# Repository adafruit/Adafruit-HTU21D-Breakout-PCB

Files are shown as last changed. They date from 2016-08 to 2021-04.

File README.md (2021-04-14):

## Adafruit HTU21D Breakout PCB
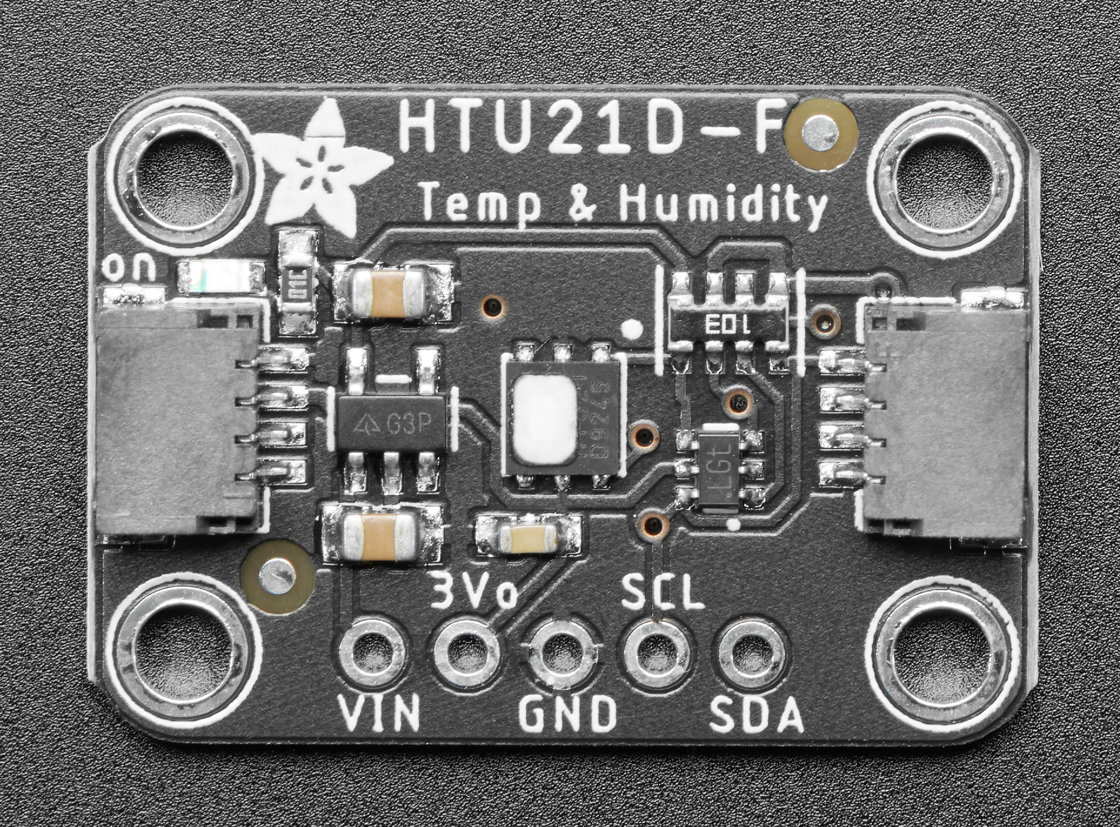
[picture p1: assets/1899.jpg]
<a href="http://www.adafruit.com/products/1899"><br/>
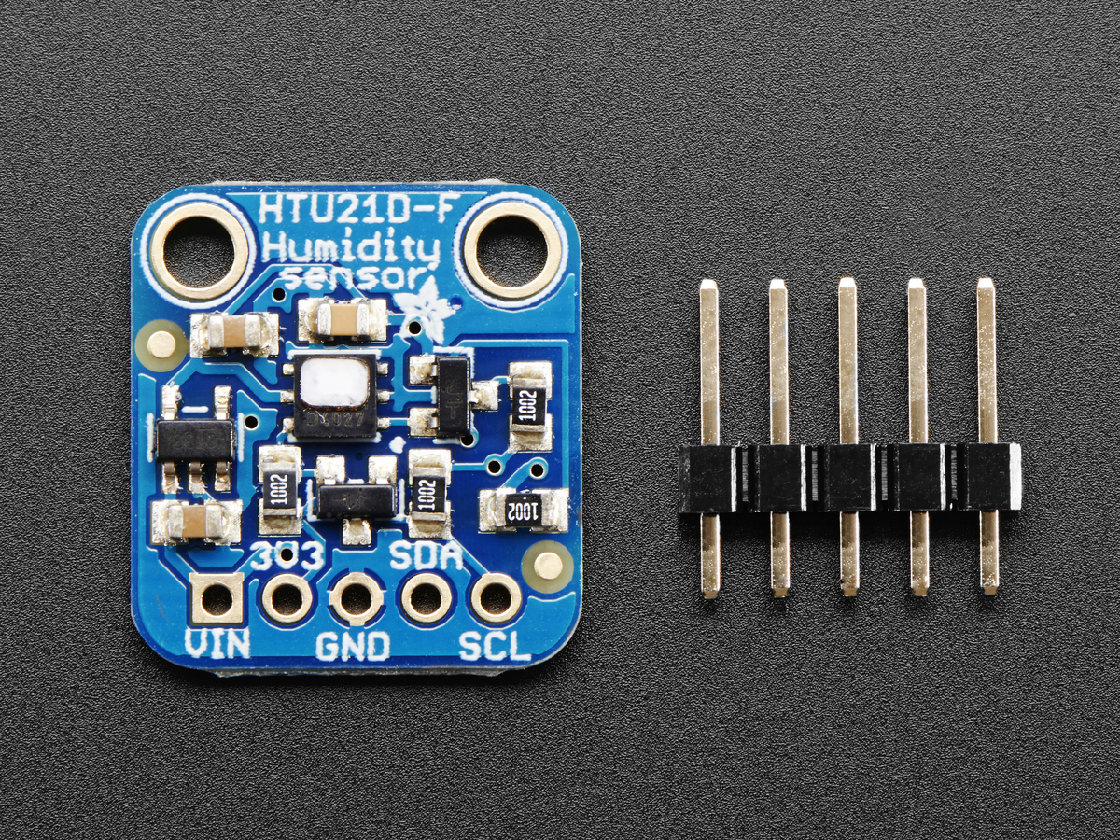
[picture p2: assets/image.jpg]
<a href="http://www.adafruit.com/products/1899"><br/>
Click here to purchase one from the Adafruit shop</a>

The HTU21D-F Temperature + Humidity Sensor - the best way to prove the weatherman wrong!

This I2C digital humidity sensor is an accurate and intelligent alternative to the much simpler Humidity and Temperature Sensor - SHT15 Breakout It has a typical accuracy of ±2% with an operating range that's optimized from 5% to 95% RH. Operation outside this range is still possible - just the accuracy might drop a bit. The temperature output has an accuracy of ±1°C from -30~90°C. If you're looking to measure temperature more accurately, we recommend the MCP9808 High Accuracy I2C Temperature Sensor Breakout Board.

To get you going fast, we spun up a custom made PCB in the STEMMA QT form factor, making them easy to interface with. The STEMMA QT connectors on either side are compatible with the SparkFun Qwiic I2C connectors. This allows you to make solderless connections between your development board and the HTU21Ds or to chain them with a wide range of other sensors and accessories using a compatible cable. QT Cable is not included, but we have a variety in the shop.

PCB files for the Adafruit HTU21D Breakout. The format is EagleCAD schematic and board layout
- https://www.adafruit.com/products/1899

### License

Adafruit invests time and resources providing this open source design, please support Adafruit and open-source hardware by purchasing products from [Adafruit](https://www.adafruit.com)!

All text above must be included in any redistribution

Designed by Limor Fried/Ladyada for Adafruit Industries.
Creative Commons Attribution/Share-Alike, all text above must be included in any redistribution. 
See license.txt for additional information.

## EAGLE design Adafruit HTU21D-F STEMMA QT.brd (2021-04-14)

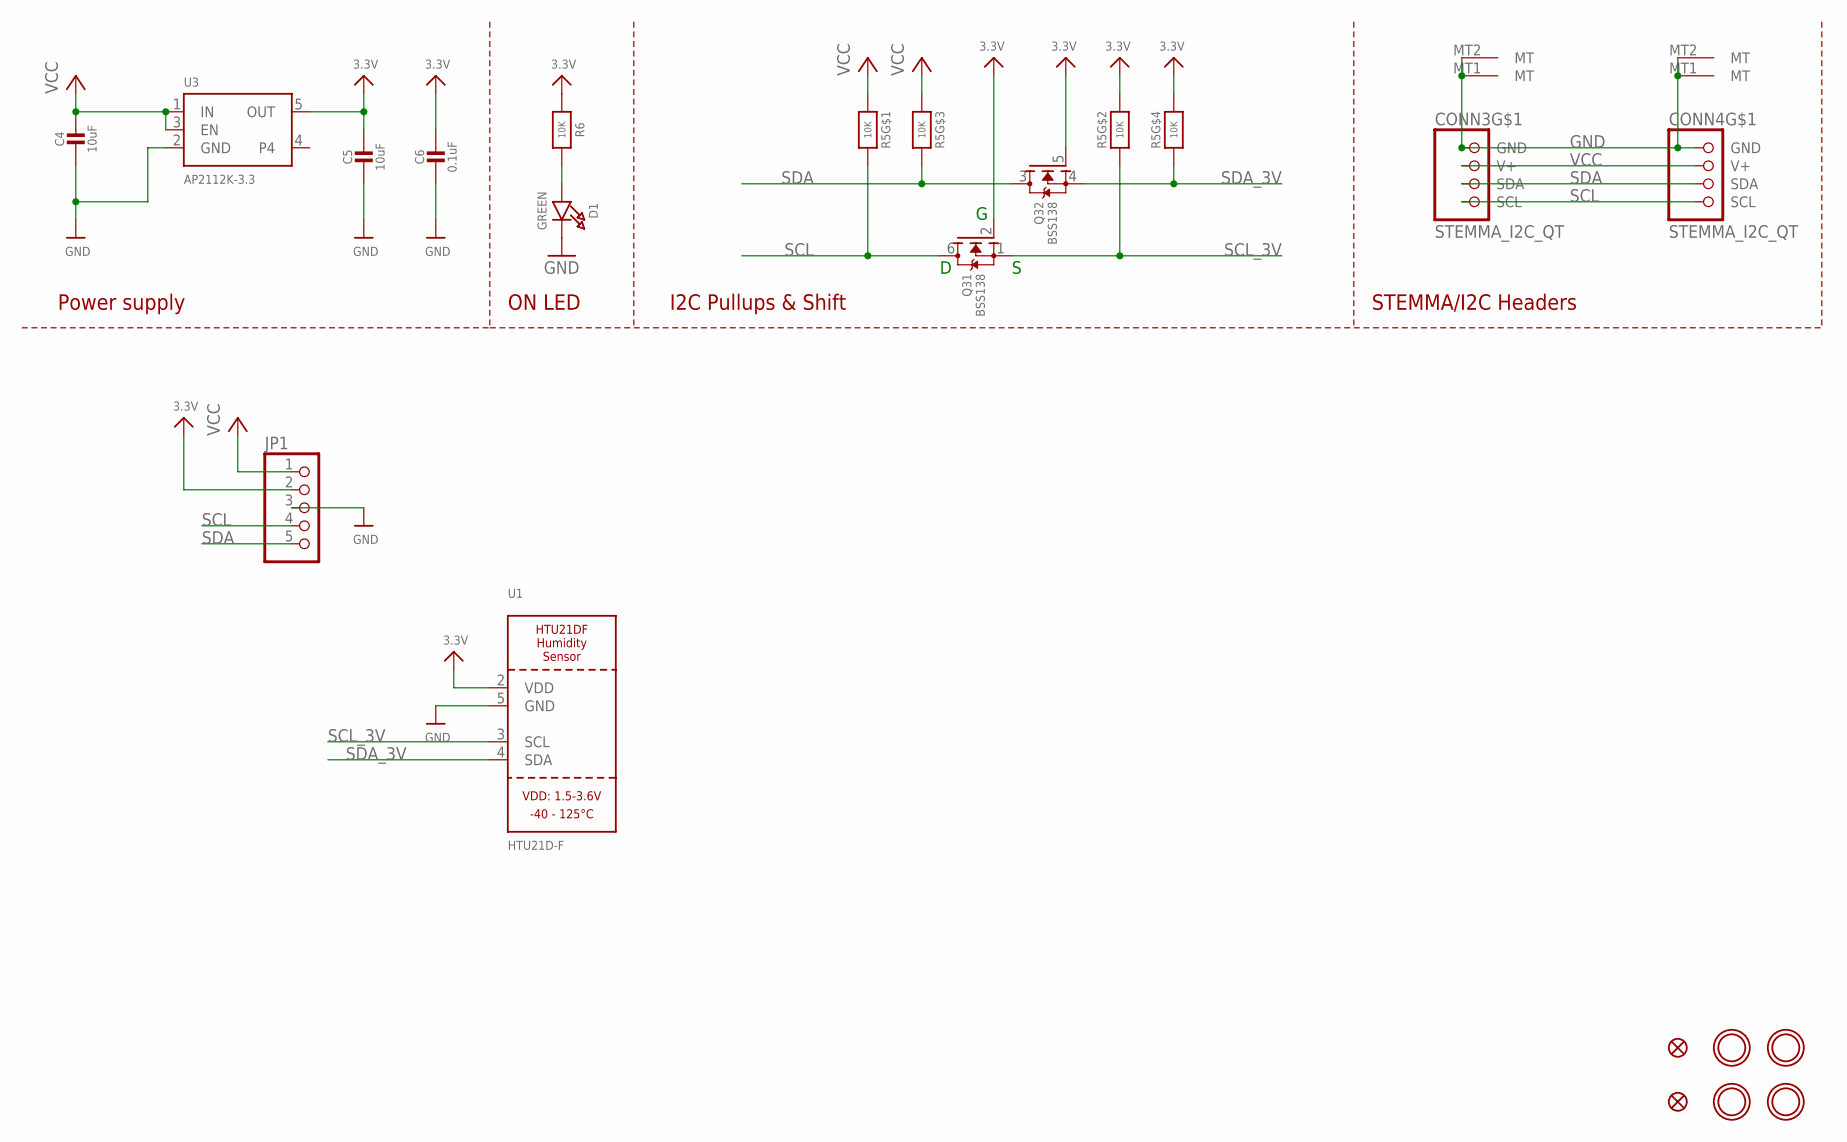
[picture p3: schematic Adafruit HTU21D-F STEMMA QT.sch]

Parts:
C4, C5: 10uF; 0805-NO
C6: 0.1uF; 0603-NO
CONN3, CONN4: STEMMA_I2C_QT; JST_SH4
D1: GREEN; CHIPLED_0603_NOOUTLINE
FID3, FID4: FIDUCIAL_1MM
JP1: HEADER-1X570MIL; 1X05_ROUND_70
Q3: BSS138; SOT363
R5: 10K; RESPACK_4X0603
R6: 10K; 0603-NO
U1: HTU21D-F; HTU21DF
U3: AP2112K-3.3; SOT23-5
U$19, U$20, U$22, U$25: MOUNTINGHOLE2.5; MOUNTINGHOLE_2.5_PLATED

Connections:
3.3V: C5.1, C6.1, JP1.2, Q3.2 (G), Q3.5 (G), R5.2 (1), R5.4 (1), R6.1, U1.2 (VDD), U3.5 (OUT)
GND: C4.2, C5.2, C6.2, CONN3.1 (GND), CONN3.MT1 (MT), CONN3.MT2 (MT), CONN4.1 (GND), CONN4.MT1 (MT), CONN4.MT2 (MT), D1.C, JP1.3, U1.5 (GND), U3.2 (GND)
unnamed: D1.A, R6.2
SCL: CONN3.4 (SCL), CONN4.4 (SCL), JP1.4, Q3.6 (D), R5.8 (2)
SCL_3V: Q3.1 (S), R5.7 (2), U1.3 (SCL)
SDA: CONN3.3 (SDA), CONN4.3 (SDA), JP1.5, Q3.3 (D), R5.6 (2)
SDA_3V: Q3.4 (S), R5.5 (2), U1.4 (SDA)
VCC: C4.1, CONN3.2 (V+), CONN4.2 (V+), JP1.1, R5.1, R5.3 (1), U3.1 (IN), U3.3 (EN)

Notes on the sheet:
I2C Pullups & Shift
STEMMA/I2C Headers
ON LED
Power supply

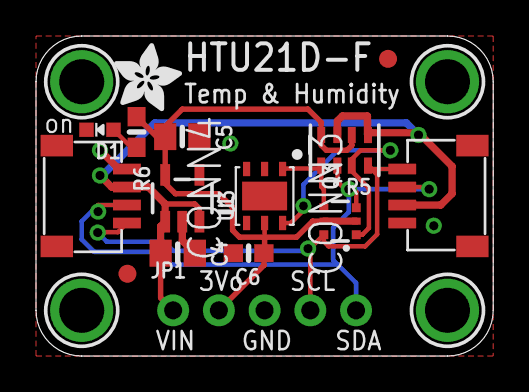
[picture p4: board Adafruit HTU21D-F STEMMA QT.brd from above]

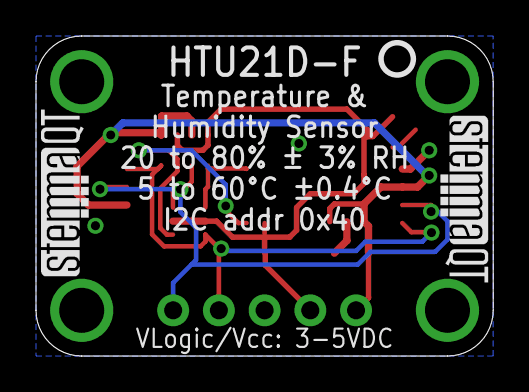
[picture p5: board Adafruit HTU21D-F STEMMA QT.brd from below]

Board: 2 copper layers, 25.4 x 17.8 mm, 22 parts (3 on the bottom side), 8 nets.

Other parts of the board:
U$28: ADAFRUIT_3.5MM
U$29: PCBFEAT-REV-040
U$30, U$31: STEMMAQT

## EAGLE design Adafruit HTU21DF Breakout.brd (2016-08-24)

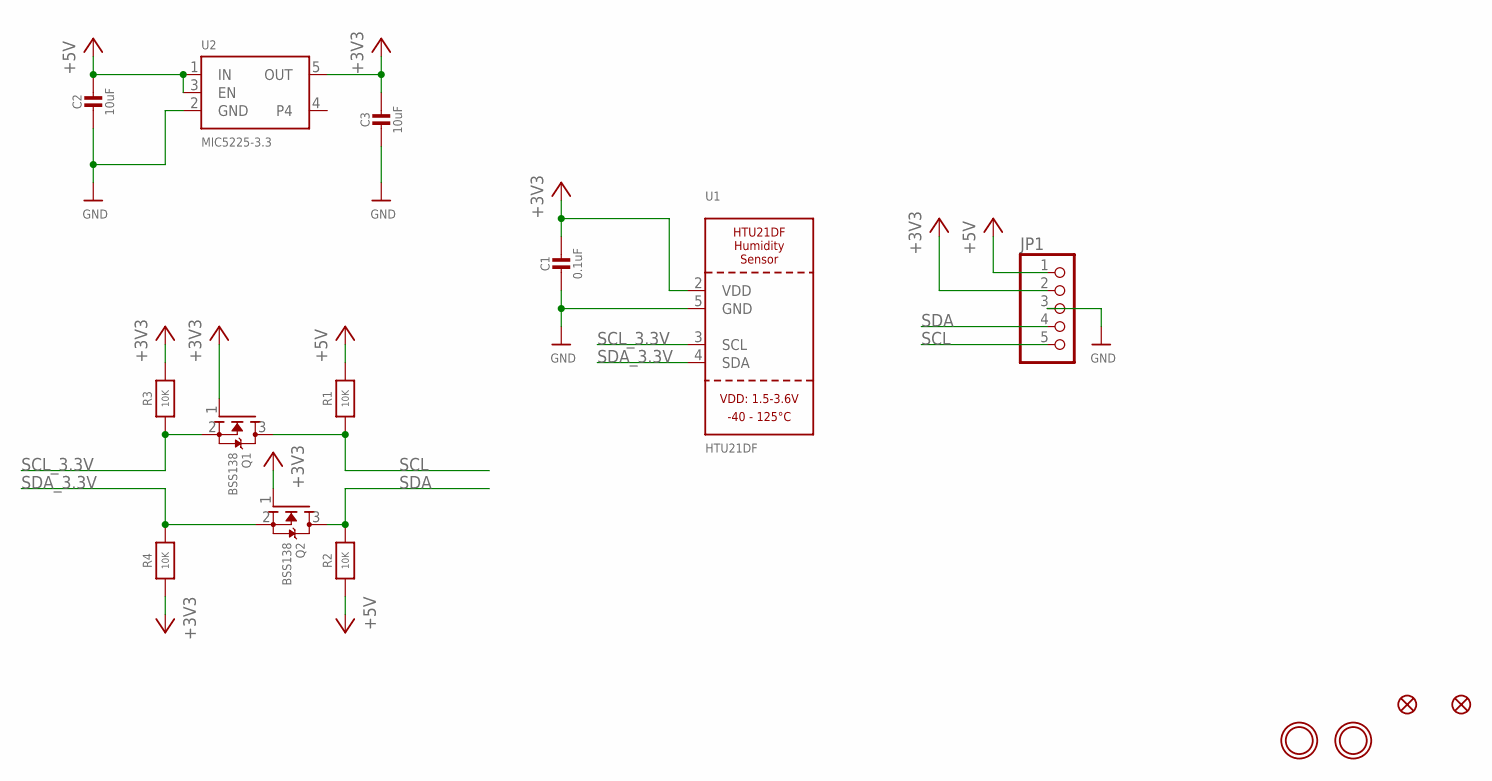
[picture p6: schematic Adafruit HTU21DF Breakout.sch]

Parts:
C1: 0.1uF; 0805-NO
C2, C3: 10uF; 0805-NO
FID1, FID2: FIDUCIAL""; FIDUCIAL_1MM
JP1: HEADER-1X570MIL; 1X05_ROUND_70
Q1, Q2: BSS138; SOT23-WIDE
R1, R2, R3, R4: 10K; 0805-NO
U1: HTU21DF
U2: MIC5225-3.3; SOT23-5
U$3, U$4: MOUNTINGHOLE2.5; MOUNTINGHOLE_2.5_PLATED

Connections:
+3V3: C1.1, C3.1, JP1.2, Q1.1 (G), Q2.1 (G), R3.2, R4.1, U1.2 (VDD), U2.5 (OUT)
GND: C1.2, C2.2, C3.2, JP1.3, U1.5 (GND), U2.2 (GND)
SCL: JP1.5, Q1.3 (D), R1.1
SCL_3.3V: Q1.2 (S), R3.1, U1.3 (SCL)
SDA: JP1.4, Q2.3 (D), R2.2
SDA_3.3V: Q2.2 (S), R4.2, U1.4 (SDA)
VIN: C2.1, JP1.1, R1.2, R2.1, U2.1 (IN), U2.3 (EN)

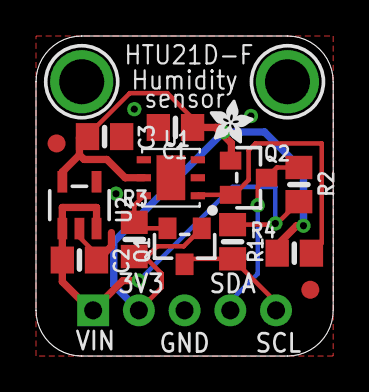
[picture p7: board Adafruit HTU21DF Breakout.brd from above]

Board: 2 copper layers, 16.5 x 17.8 mm, 18 parts (1 on the bottom side), 7 nets.

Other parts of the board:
U$1: ADAFRUIT_3.5MM
U$8: ADAFRUIT_2.5MM

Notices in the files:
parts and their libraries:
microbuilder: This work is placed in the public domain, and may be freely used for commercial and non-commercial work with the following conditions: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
